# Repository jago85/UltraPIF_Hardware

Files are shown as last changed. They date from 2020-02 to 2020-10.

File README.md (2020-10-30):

# UltraPIF_Hardware
The UltraPIF is a replacement for the N64 PIF-NUS chip.

The PIF-NUS chip responsible for region lockout and copy protection. But it also has essential features like game controller access, cartridge EEPROM access and it includes the MIPS CPU boot rom.

The UltraPIF can replace all functions of the original PIF, but ignores the CIC and thus enables a region-free N64. In addition the UltraPIF comes with an integrated clock generator to compensate the differences of the video clocks for NTSC and PAL consoles. The UltraPIF includes an SPI NOR FLASH used to store the N64 software images. At the moment the FLASH is 16 MiB in size and 99% empty, so there could be features like backup and restore of savegame data or even direct emulation of SI (serial interface) hardware (ControllerPak, cart EEPROM, RTC). An RGB LED replaces the original N64 power LED and is used to show if the N64 is running in NTSC or PAL mode. The color is user programmable.

The project consists of custom PCBs, an FPGA design, an MCU firmware and a bunch of software for the N64 itself.

In this repository you find the KiCad hardware files.

You can find hints for assembly and installation in [the wiki](https://github.com/jago85/UltraPIF_Hardware/wiki).

Interface Board
Adapter Board
LED Board
Interface installed

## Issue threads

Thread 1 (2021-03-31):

Unavailable parts

BadAd84, 2021-03-31:
Hi,

Looking at getting a batch of these made for our store. However, the STM32F070CBT6 and SI5351A-B-GTR are basically not available for a year+ due to shortages.

Is there any sort of alternative or redesign planned? I assume you are seeing this issue too (or maybe not, as not making many??)

jago85, 2021-04-23:
Hi,

sorry for the delay. Due to a lack of time, I'm pretty inactive right now.

Unfortunatelly, I don't have any alternatives or redesign. There may be some compatible devices for the STM32, but I have no idea how to replace the clock generator. Having different parts would also make firmware updates much more complex. I wouldn't have the time for a re-design anyway. I didn't even manage to sort and upload all the software stuff here. (All N64 software and initialization tools are missing here.)

But I know Romi from ModInFrance managed to produce a batch and he can make a good reseller price. You might ask him if you like. [https://shop.modinfrance.fr/fr/nintendo-64/25-115-ultra-pif-nintendo-64.html](https://shop.modinfrance.fr/fr/nintendo-64/25-115-ultra-pif-nintendo-64.html)

BadAd84, 2021-04-23:
That all makes sense, especially around firmware. I have an order in that's just waiting on stock.

Could you send me the extra tools/files required? I could always fork and add it and submit a pull request if it helps you with time etc. I have been maintaining the cdi and 3do rgb mod repos since the owners discontinued them

jago85, 2021-04-26:
Sorry, I cannot send out the firmware at the moment. You should talk to Romi for further details.

Closed 2022-01-19.

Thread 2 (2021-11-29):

Ultra Pif no video but hear slowed down audio

iVirtualPlays, 2021-11-29:
Did the Ultra Pif mod exactly as instructed but doesn’t work. I get no video but hear audio except it’s in slow motion. This Ultra Pif was taken out of my fried Pal Console which i failed to install a ReN64 psu mod and the i put the Ultra Pif into my replacement NTSC motherboard. I then started having this problem once it was transferred. I tried converting the NTSC console into a Pal one by replacing the U7, U15 and the X2 Oscillator, and i get the same problem. Is my Ultra Pif at fault or did i miss something? I don’t know what the JP 4,3,2,1 bridge points are, don’t know what the BL point is on the Ultra Pif board and i get a flashing LD2 Red Status LED with the Green LD3.
By the way my motherboard is NUS-CPU-05 and my faulty Pal motherboard is NUS-CPU (P)01 revision. Hopefully i can fix that motherboard someday.

Here are some pics.
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

iVirtualPlays, 2021-11-29:
By the way my motherboard is NUS-CPU-05 and my faulty Pal motherboard is NUS-CPU (P)01 revision.

jago85, 2021-11-29:
Hi,

the UltraPIF seems to run, but the video clock is not working. Did you remove the load capacitors from X1 on the back of the motherboard? (C39, C40)

Could also be a bad contact in the connector. Sometimes I need to clean them with Isopropyl alcohol.

X2 and U15 are for the RDRAM-Clock. These parts should be the same for PAL and NTSC. Replacing them will not have any effect.

iVirtualPlays, 2021-11-29:
Thanks looks like i may have screwed up the adaptor board. As i desoldered it off my dead N64 using a rework station, the connector is a bit burned. I tried reflowing it with drag soldering and i ended up bridging every joint. Can’t seem to unbridge them since the gaps are too small. So do you know where i can purchase a replacement adaptor board?

Sent from my iPhone

On 29 Nov 2021, at 19:03, Jan Goldacker ***@***.***> wrote:

Hi,

the UltraPIF seems to run, but the video clock is not working. Did you remove the load capacitors from X1 on the back of the motherboard? (C39, C40)

Could also be a bad contact in the connector. Sometimes I need to clean them with Isopropyl alcohol.

X2 and U15 are for the RDRAM-Clock. These parts should be the same for PAL and NTSC. Replacing them will not have any effect.

—
You are receiving this because you authored the thread.
Reply to this email directly, view it on GitHub<https://github.com/jago85/UltraPIF_Hardware/issues/2#issuecomment-981926268>, or unsubscribe<https://github.com/notifications/unsubscribe-auth/AQAQAAXFZOA5QLP5DHJM33LUOPFAHANCNFSM5I7LFBQQ>.
Triage notifications on the go with GitHub Mobile for iOS<https://apps.apple.com/app/apple-store/id1477376905?ct=notification-email&mt=8&pt=524675> or Android<https://play.google.com/store/apps/details?id=com.github.android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>.

iVirtualPlays, 2021-11-29:
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

jago85, 2021-11-29:
You may ask Romi from ModInFrance https://shop.modinfrance.fr/fr/

Yeah, it's quite difficult to remove these boards intact.

You are not from Germany, are you?

iVirtualPlays, 2021-11-29:
No i’m from the UK. I spoke to him they just have the connectors. But will need to figure a way to solder those on. Would be preferred if i can get a preassemble board.

iVirtualPlays, 2021-11-29:
Looks like i will be able to order some replacement adaptor boards, will see if that fixes it. Thanks.

Closed 2022-01-19.

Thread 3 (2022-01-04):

Bad Sync on NTSC games

ZXPortugal, 2022-01-04:
Hi! I own a Jap RGB capable N64, whitch i have a bortis RGB amp installed. Before the Ultra Pif was installed, everything was working ok.
Now with the Ultra Pif i have the following issues:

Menu boots fine with PAL settings and all is ok, PAL games works like charm.
When select NTSC for the menu or NTSC game, i cant get sync.

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

Thanks.

jago85, 2022-01-05:
I think your FSEL signal is somehow tight to GND. Can you check this? The problem might be in one of the connectors as this signal goes between two GND connections.

ZXPortugal, 2022-01-05:
Hi. I have checked and have 2 readings.

I have tested the FSEL to see if gives me GND signal.
With the Ultra Pif removed, i have no ground signal betwen FSEL and GND (used the pin 2 of the MX8330) but with the interface mounted i have a small reading on the multímeter continuity between FSEL and GND

Thanks in advance

Obter Outlook para Android<https://aka.ms/AAb9ysg>
________________________________
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

jago85, 2022-01-05:
So, it looks as there is a short on the Interface board. You can verify this by removing the board and then measure continuity from U1 pin 6 to GND.
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

Maybe there is a solder bridge here:
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

I think you have 3 options:

1. Find and remove the short by yourself
2. Ask your seller for a replacement
3. Use the alternative (not yet documented) installation method that does not require FSEL.
   - close JP1 on the Interface
   - directly connect XTAL to VCLK
      - Lift and isolate pin 1 of the MX8330
      - Then connect XTAL to the VCLK pad on the motherboard
      - Pin 1 stays unconnected

ZXPortugal, 2022-01-06:
Hi!

Have have checked for any bridges and found none.
So i testes the experimental method.

Shorted JP1, lifted PIN 1 of the mx8330, solder the Wire from XTAL to VCLK of NUS IC, and have sucess!!

Now NTSC is working and PAL! Thanks

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
![Uploading IMG_20220106_155955.jpg…]()

jago85, 2022-01-09:
Hi!
Great news! I still wonder why FSEL doesn't work. If it's not a short, maybe there's a problem with the contact or a dead pin. Anyway, I'm glad it's working now.

Closed 2022-01-19.

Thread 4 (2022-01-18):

Analogue audio drop out UltraPIF + N64Digital

ConsoleRefresh, 2022-01-18:
Hi I have a problem. I’ve installed an UltraPIF acquired recently from ModinFrance with N64Digital on a Pal board. I’ve wired up the N64Digital to control the video clock speed and it works as expected. The N64Digital output is beautiful and I adore it. Problem is the analogue audio always drops out after 12-15 mins of play affecting RGB / composite. The composite output for NTSC games is also black and white which isn’t a problem for me but wondering if that indicates an underlying problem. Any help will be greatly appreciated.

jago85, 2022-01-19:
Hi,

I don't have an N64Digital to test this. You shouldn't use the video clock from the N64Digital when you have an UltraPIF. The UltraPIF generates it's own clock.

What N64 motherboard revision do you have?

I don't have any idea what's wrong with your audio. The UltraPIF should not affect the audio.

So you still have the audio on HDMI?

If you want to use Composite Video, you have the connect the NTSC/PAL select signal of the video encoder to FSEL. I just added this information to the Installation Guide in the wiki. https://github.com/jago85/UltraPIF_Hardware/wiki/Installation#composites-video-ntscpal-switch

ConsoleRefresh, 2022-01-19:
Hi thanks for getting back to me. It’s a Pal 01 board. The HDMI audio is flawless. On analogue after 12 mins or so the audio quietens, disappears and occasionally comes back for a few milliseconds. If I then switch over to HDMI the audio is still fine. I’ve tried different analogue leads and it’s definitely the console’s audio that drops out and not anything else. Re clock control. I was advised by ModinFrance to use the N64Digital clock control as there was an issue with UltraPIF controlling the clock with N64D installed. Is this not the case? The N64Digital automatically detecting the region and clock control works beautifully with UltraPIF. Could the audio problem be the console’s amplifier drops out? This audio problem also happens on another console I’ve modded the same way. I’m perplexed.

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

jago85, 2022-01-19:
Hi,

I have a PAL-01 here modded with UltraPIF and N64Adv (RGB mod). Never had any problems with the audio there.

If there is audio on HDMI, then it must drop out somewhere from U1 to U2. I do not have any experience how this subsystem works. Do you have an oscilloscope to check the analogue waveforms?
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

Audio L goes from U1.4 to C32, from C32 to U2.12. Audio R goes from U1.1 to C31, from C31 to U2.3. Then from U2 left audio leaves at pin 8 and right at pin 7.
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

Also, I'd check the 12V on U2.1. Did you use the same power supply for your second console? I'd be super surprised if this issue would be caused by the UltraPIF. The N64Digital is directly connected to the digital audio (U9 pin 6, 7, 10).

I'll ask ModInFrance about the clock. The clock from UltraPIF was to week to drive the N64Digital. I thought the issue was fixed with the firmware changes. I said, I don't know much about the N64Digital. So, I don't understand how it could ever detect the region? According to my information, you have to set the clock manually via Bluetooth. When using a flash cart, the N64Digital cannot know what game you are going to play. You have to select the region in the UltraPIF before starting the flash cart and the N64Digital will not see anything of this. Maybe I missed something, but at the moment this doesn't make sense to me.

jago85, 2022-01-19:
Also, on the PAL-01 board, the clock strength is not a problem, because it has the MX8330 and the video clock doesn't need to be driven directly by the UltraPIF.

ConsoleRefresh, 2022-01-25:
Hi thank you for all the info. The problem seems to have resolved itself on both consoles so it must be a dodgy PSU as the chances of both consoles miraculously resolving themselves at the same time seems ridiculous. I’ve re-capped the PSU now and hopefully it’ll never happen again!

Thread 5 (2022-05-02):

Interaction with Everdrive X7 (UltraCIC-III) and booting PAL ROMs

crozone, 2022-05-02:
I am looking to install the UltraPIF into a PAL N64 to make it multi-region. The system will see use with an Everdrive X7.

I'm hoping just to clarify the behaviour of the UltraPIF in certain scenarios when used with the Everdrive X7 or similar flash cart. It's a bit complicated because the Everdrive does region detection at boot, but it can also launch any region of game after it has started up. I'm especially wondering what the behaviour will be if I launch a PAL game from an Everdrive X7 (UltraCIC-III) on a UltraPIF modded system.

Here are my current assumptions, I'm hoping if you could offer some guidance on whether they are correct or not:

### 1: UltraCIC-III will always choose NTSC on UltraPIF

My rudimentary understanding of the UltraCIC-III is that it achieves automatic region detection by first attempting to boot into NTSC mode, and if that fails, it switches over to PAL mode and reboots.

I *think* this is the UltraCIC-III code that is running in the Everdrive, and it has NTSC mode set as the initial region:

https://github.com/ManCloud/UltraCIC-III/blob/16fd1eecd8528ab2d7fd0490f24fb7738017bd39/UltraCIC-III.asm#L1038

So it looks like it'll always boot into NTSC mode when used with UltraPIF?

### 2: UltraPIF uses the CIC check to set frequencies

This one I'm not really sure about from looking at the project, but does the UltraPIF use the CIC check to set the NTSC/PAL mode (FSEL and clock, etc)? Or does it choose the mode based on the actual game behavior?

### 3: Booting PAL games

The Everdrive X7 is capable of booting PAL games on an NTSC console, and vice versa, through some magic that the Everdrive firmware does. On an un-modded N64 this leads to some weird video output because the frequencies are slightly off and the video encoder chip is still set to the console's region. I believe this causes PAL on NTSC to output as NTSC50, and NTSC on PAL to output as PAL60, and TVs don't always deal with this very well.

My assumption is that the UltraPIF won't/can't know that the Everdrive is actually booting a PAL game from NTSC mode, and will therefore always stay in NTSC mode. This will lead to PAL games booted from the Everdrive to behave as if they're running on an un-modded NTSC system, with the weird video output. Am I correct on this, or does the UltraPIF derive the region via some other method?

Thank you for any assistance you can offer.

jago85, 2022-05-07:
Hi,

the UltraPIF doesn't care about the CIC . You don't even need to have a CIC installed.

The region is setup in the UltraPIF menu everytime before booting a ROM. The UltraPIF determines the region based on the country code in the ROM header to make a pre-selection of the correct region. If I remember correctly, the Everdrive has an empty country code. In this case the UltraPIF can eighter use a fixed region or remember the last region.

It's correct, that the UltraPIF doesn't know when the ED switches the region. So, if you want to play PAL games you have to start the ED in PAL mode (selected in the UltraPIF menu).

The ED could send commands to the UltraPIF and actively reset into the other region, but this is not implemented at the moment.

Ok, I hope this short response answers your question. Feel free to ask more if it is unclear.

crozone, 2022-05-09:
Thanks! I wasn't aware that the UltraPIF implemented its own menu at boot. I finally found a video of it in action [here](https://youtu.be/k5jYbVk9AjA?t=961), and it all makes sense now.

> It's correct, that the UltraPIF doesn't know when the ED switches the region. So, if you want to play PAL games you have to start the ED in PAL mode (selected in the UltraPIF menu).

That's exactly what I was wondering, cheers. Looks like an UltraPIF will work pretty well with an ED then!

Closed 2022-05-09.

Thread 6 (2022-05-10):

MX8330 and MX9911

Yohko, 2022-05-10:
I have a PAL N64 (NUS-CPU (P)-01) which has a MX8330 for U15 but a MX9911 for U7. I tried the Direct VLCK method (DENC-NUS) and lifted pin 1 on U7 (MX911) and connected the pad to Xtal (pin 16 on DENC-NUS is connected to FSEL).  However this doesn't give any Video/Audio. Neither Composite/S-Video/RGB or HDMI (have an additional N64Digital installed). Putting pin 1 on U7 back restores all video signals. PAL and NTSC games boot and seem to run under 50 or 60Hz (according to N64Digital). Composite is in color (via RT5x). Lifting Pin 1 on U7 and bridging the jumper  on the N64Digital also works. However here composite is then in black and white. I didn't try and connected stall to the pin 1 pad and have the jumper on the N64digital closed at the same time as that probably will also cause a crash? Any thoughts on this?

jago85, 2022-05-14:
Hi,

hm, have some thouhgts. But it's not totally clear to me.

The MX9911 should not make a difference. It's the same as the MX8330 but has no output on pin 3. When lifting pin 1, the chip is has no influence to the video clock.

Did you close JP1 on UltraPIF for the Direct VCLK method?

As far as I know, the N64Digital does not work with the clock from the UltraPIF. I think it's putting too much load an the line or has too high termination/damping resistance. But I cannot test it, because I don't have one.

Did you test with the N64Digital disconnected? If it doesn't work, maybe the UltraPIF clock output has an issue.

Do you have a scope to meassure the clock?

Did you try the Standard VCLK method? I cannot test this too, becaus I have no MX9911 here.

Yohko, 2022-05-17:
I have JP1 closed. But I never tried the standard method (as I didn't want to remove any parts). Pin1 is lifted and the N64Digital JP on the flex is closed. I got basically the same issue now on an NTSC (US) N64 with the two MX8330. In both cases I ended up using the N64Digital for the clock. I don't have a scope here but I eventually can try and disconnect the N64Digital and connect the UltraPif to Pin1 and see if it works again. Its not that 50/60Hz doesn't work, just that the N64Digital has to be connected to Pin1 instead.

Yohko, 2022-05-24:
I did some work on the NTSC-US N64 today and did some tests again.
(1) N64digital disconnected (only the flex is still attached to the RCP, jp1 on flex is open), Direct VLCK method with Ultrapif (jp1 on ultrapif is closed, xtal connected to pin1 pad on board, pin 1 lifted and disconnected): no picture (composite)
(2) same as above but N64digital attached: no picture
(3) xtal disconnected from pin1 pad, jp1 on N64digital closed: picture for composite as well as RGB and HDMI from N64digital. PAL composite is black and white and flickers as expected. Everything else looks good.

In all three scenarios (1-3) doing boot up LD2 on ultrapif flashes and the power led cycles through the colors.

jago85, 2022-05-26:
Everything you wrote sounds done right. Maybe there really is something wrong with the UltraPIF / the clock gen. Hard to tell without having it here and without the ability to measure something.

I did some tests today. I disconnected the XTAL signal on both installation methods. With the Direct VCLK method the N64 is stuck after boot. LD2 doesn't flash and the power LED doesn't cycle through the colors.
With the Standard Method LD2 flashes and the power LED cycles but everything is slightly slower than normal. This is because the MX8330 outputs some clock even if there is no input.
So I think there must be some clock on your VCLK. Maybe not the right frequency. Can you tell if the power LED color cycling is slower when the clock comes from the UltraPIF? When you then disconnect the clock completely the N64 should stop after boot. (Just to verify that there really isn't anything connected to the clock.)

I don't have any really good ideas now. Maybe you could do some continuity checks.

The wire from XTAL should have continuity to pin 9 on UltraPIF U1.
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

Maybe the FPGA has no connection to JP1 and thus cannot read that it is closed. If JP1 is closed there should be continuity between GND and pin 64 of U2.
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

I have no clue at the moment. But as long as the N64Digital isn't working with the clock from the UltraPIF you cannot use the Direct VCLK method anyway. Eighter you keep using the N64Digital's VCLK or you try the Standard Method. (The N64Digital's clock will work without the removed parts, too.)

Yohko, 2024-05-19:
During the last few years I have now installed the UltraPIF in several systems with UltraHDMI, N64Digital, and GEM. If I don't want to use the "Standard VCLK method" (as I don't want to remove components) then only direct VLCK with JP1 closed, but no wires connected from XTAL to Pin1 will work. FSEL connected to the encoder if I wanted to fix the composite (on a compatible encoder). Others came to the same result. Standard method seems to work but then the HDMI mod looses its functionality to switch the clk. With direct mode it's the other way around (if UltraPIF is not connected to Pin 1, else back picture, e.g. real direct mode is still broken with HDMI mods).
Did you look into this further and maybe tested this with a HDMI mod yourself (e.g. if direct mode can be made functional?

jago85, 2024-05-19:
I'm not sure if I understand everything correctly. Please allow me this question: You don't happen to speak German, do you? Your name sounds like you could be German. No problem if that's not the case. It would just be easier for me to understand and explain the complicated things.

>_only direct VLCK with JP1 closed, but no wires connected from XTAL to Pin1 will work._

Which JP1 do you mean: UltraPIF or N64Digital? If you don't connect XTAL, it is useless to close JP1 on UltraPIF. If you use the clock from the HDMI mod JP1 on the UltraPIF is a Don't Care. XTAL is left unconnected.

>_Standard method seems to work but then the HDMI mod looses its functionality to switch the clk._

Of course, when using the clock from the console it's impossible to use it from the HDMI mod at the same time. If you are using Direct VCLK from UltraPIF you will lose that feature, too. You always have to decide where the clock should come from. But if you have an UltraPIF, I don't see the point of using the HDMI mod to generate that clock. (Except for the fact it doesn't work any other way for some reason).

>_With direct mode it's the other way around (if UltraPIF is not connected to Pin 1, else back picture, e.g. real direct mode is still broken with HDMI mods)._

I don't fully understand this. With direct mode, you mean the HDMI mod driving this clock? From the UltraPIF's point of view, this is not a mode at all. It is simply unused. And yes, it cannot control the clock in this case. As said, you have to make a decision.

>_If only one mod will be able to control the CLK then this is probably how it's supposed to be, e.g. Standard mode if UltraPIF should control it, JP1 closed (but not wired up) if HDMI mod is controlling it._

As said before, when using the clock from HDMI mod the setup of JP1 on UltraPIF doesn't play a rule. Or did you mean JP1 of the N64Digital?

>_Did you look into this further and maybe tested this with a HDMI mod yourself?_

I have several mods based on CPLD or FPGA using that clock. N64 Advanced v2 (HDMI mod), N64 Advanced v1 (RGB mod), N64 RGB mods from F_L_a_S_H. Everything works without problems, regardless of whether the VCLK is output from the MX chip or directly from UltraPIF. I have just tried it with 3 different consoles.

I got reported the N64Digital not liking the VCLK from UltraPIF years ago. I increased the drive strength of the SI5351A (which is generating the clock) to the maximum. It then worked if I remember correctly.

I probably won't have an N64Digital or Retro GEM unless one is made available to me. (It would also be possible to swap an HDMI mod for say 2 UltraPIFs if the devs are interested in a test system with an UltraPIF.) One thing I've done differently is to connect everything via individual wires. I'm not using flex cables as I only have experimental setups here. My wiring looks rather messy and yet it works fine. So my assumption remains that the clock signal may be too strongly attenuated by a resistor in the flex cable or some other component. As long as no one can measure the signal with an oscilloscope as it arrives at the HDMI mod, I have no new ideas.

jago85, 2024-05-19:
Can you follow how the clock line runs from the N64 board to the FPGA of the HDMI mod? Through any resistors? I can see there is at least one resistor on the flex cable where the clock goes through. But I don't know where the signal ends on the FPGA. Is there a termination on the HDMI board? Any R-C combination or something?

You could also try connecting the clock from the UltraPIF to the HDMI board with a dedicated wire. You could also try using an additional separate GND wire with the clock.

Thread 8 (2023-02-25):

Reset Ultrapif settings

Parodius79, 2023-02-25:
How can you reset the ULTRAPIF settings? Upon boot I toggled the 'direct boot to cart' option in the settings, but I do not know how to undo this option or get back to the settings menu afterwards to make any further changes.

Grateful for assistance as I am unable to find any user information online.

jago85, 2023-02-26:
Hi,
you can return to the menu by holding down the reset button for two seconds while the game is running. (Release the button after the RGB LED starts to flash.)

Also, you can get into the menu by booting the N64 without a cartridge.

Hope this helps :)

Parodius79, 2023-02-26:
Yes, that works - thanks!

Closed 2023-02-26.

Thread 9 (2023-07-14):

Flickering screen + hot N64 NTSC mode

Roy-Meijer, 2023-07-14:
I have a PAL N64 with Tim Worthington's N64RGB and I have installed the Ultra PIF chip on it. Now when it switches to NTSC mode, the screen becomes unstable and flickering. I have noticed the flickering is specifically visible on black screens. Also my N64 becomes relatively hot.

My N64 has a MX8350 PLL chip and MAV-NUS video chip. In have installed it with the direct VCLK method and with composite video. First I removed the PIF chip and soldered on the adapter board. Next I connected JP1 of the UltraPIF PCB and then I lifted pin 3 (VLCK) of the PLL chip and connected the pad to XTAL, lifted pin 23 (mode select) of the MAV-NUS chip and connected the lifted pin to FSEL. Finally installed the UltraPIF PCB on the adapter board. Do you have an idea what is wrong?

Roy-Meijer, 2023-07-14:
I found out the flicker issue is related to the N64 RGB mod

Closed 2023-07-14.

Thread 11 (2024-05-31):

Boot to game not working

vraskin2024, 2024-05-31:
Hi Jago85!
I just installed the UltraPIF into my US N64 and everything works great except for the "Boot to Game" option. The "Reset to Game" option works as intended, but after trying every combination of settings I still have to go through the UltraPIF menu. I was wondering if this was a known software issue or maybe something that could be caused by an incorrect installation? I also have Tim Worthington's N64RGB mod installed if that makes a difference.

Thanks!

vraskin2024, 2024-06-01:
Thanks for the quick response!

1. When powered on, it boots to the menu regarding of what settings are selected. When reset via the reset button, it behaves correctly based on the "Reset to Game: On/Off" setting. The "Boot to Game: On/ Off" setting does get saved, it just doesn't get applied.

2. I've tried with a several US games, a Japanese game, and an Everdrive.

3. I'm pretty sure it was on the latest firmware when I got it, but I did a firmware update to the latest version I could find anyway in case that was the issue. Behavior was the same before and after firmware update.

Info:
Build = Mar 10 2021 19:17:13
Menu 0.9.0 FPGA 0.6.0 MCU 0.11.0

Reset Source: 1
Flash Total: 15689 KiB
Flash Used: 113 KiB (0.72%)
Bootcode CRC: 90BB6CB5

DD Test:
Name: [blank]
ID: [blank]
Bootcode CRC: DB1768F5
4KB CRC: F4B32E99
Init PI Set: 00000000
DD Status: 05080508

TV: NTSC
CIC: 83xx

4. I don't see why it would matter, but just in case it makes a difference:
- I didn't connect the RGB LED board, opting to just keep the regular LED.
- The RGB Mod I have does require a wire going to the PIF chip - I think to enable in game reset via controller? Since the original PIF is removed as part of the UltraPIF installation, I just wired it to the pad.

jago85, 2024-06-01:
Thx for the additional information.

There is a newer release over there in the UltraPIF_MCU repo.
https://github.com/jago85/UltraPIF_MCU/releases/download/v0.11.1/fw_updater_fpga_0-6-0_mcu_0-11-1_menu_0-10-1_bootfiles.zip

I would try to update it, but I don't expect any change in behavior related to this issue.

**Reset Source: 1**
This value is interesting because it is checked for the Boot-to-game feature. The value must be 0 (RESET_SOURCE_POR) but it actually is 1 (RESET_SOURCE_BUTTON). Is this the case directly after turning the console on? This could be an explanation.

I think I could reproduce an behavior like that by hitting the reset button just the right moment during boot. Does your RGB mod work without the reset connection? The UltraPIF can trigger a reset via controller too. Just hold A+B+Z+R+L for 2 seconds.

vraskin2024, 2024-06-02:
Success! Removing the wire from the N64RGB board to the PIF pad did the trick! Thank you so much! For anyone reading this, both mods play nicely together aside from this. The N64RGB de-blur function still works and the in game reset works via the UltraPIF mod.

Thank you so much for your help!

Closed 2024-06-02.

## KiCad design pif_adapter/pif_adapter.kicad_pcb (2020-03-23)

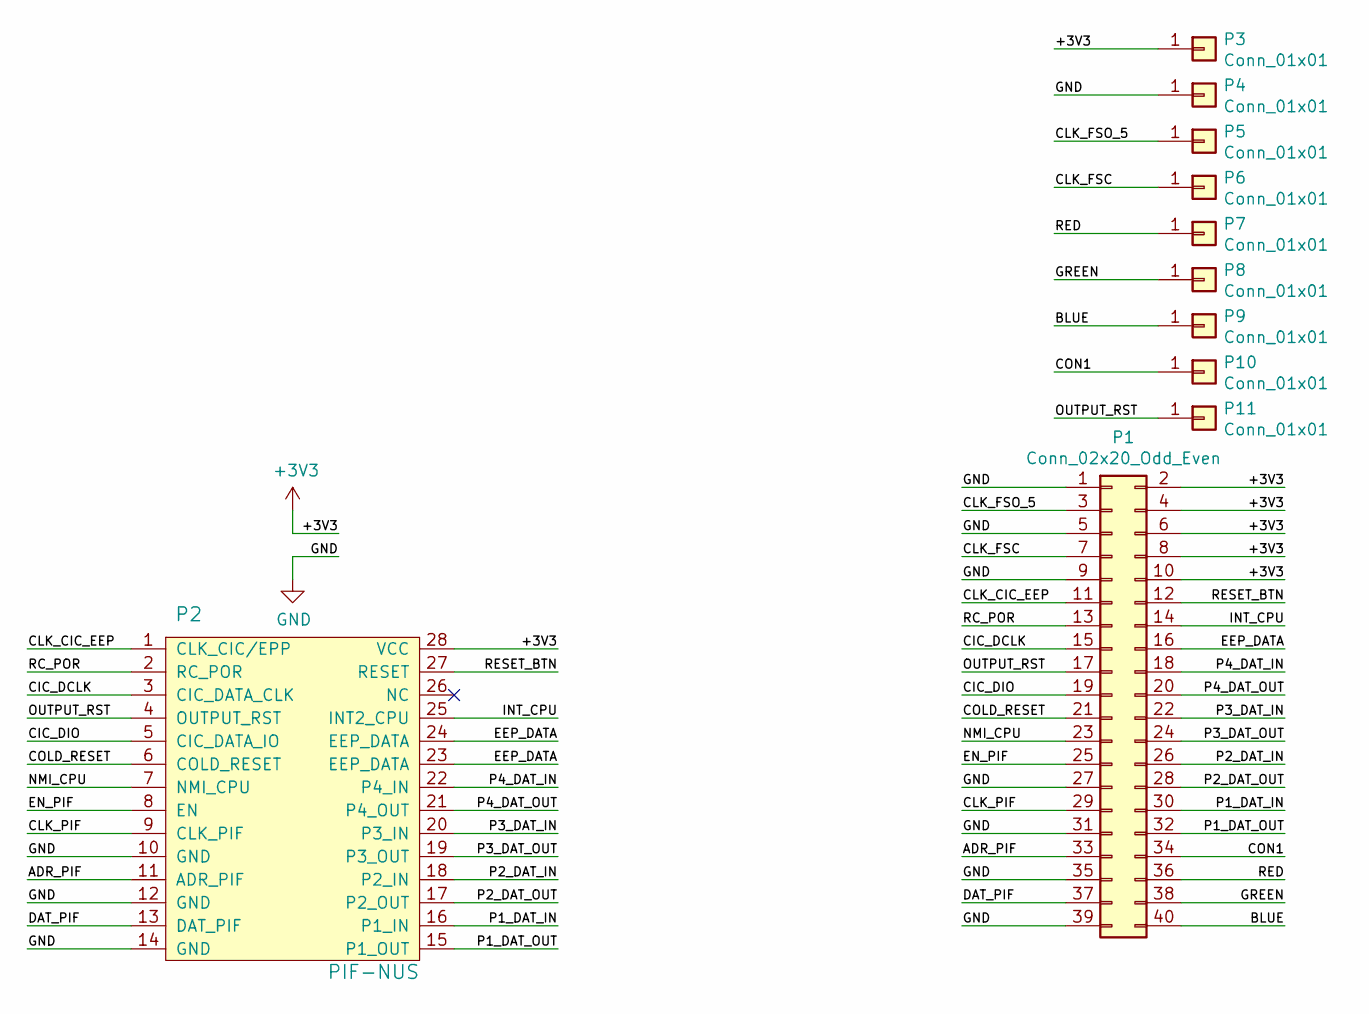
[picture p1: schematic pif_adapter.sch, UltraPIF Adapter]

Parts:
P1: Conn_02x20_Odd_Even; Hirose_DF12D-40DP-0.5V_2x20_P0.50mm_Vertical
P2: PIF-NUS; SOIC28_11mm-Width_Solder_Adapter
P3, P4, P5, P6: Conn_01x01; SolderWirePad_1x01_SMD_1x2mm
P7, P8, P9, P10, P11: Conn_01x01; SolderWirePad_1x01_SMD_0.8x1.3mm

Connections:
+3V3: P1.2, P1.4, P1.6, P1.8, P1.10, P2.28 (VCC), P3.1
/ADR_PIF: P1.33, P2.11 (ADR_PIF)
/BLUE: P1.40, P9.1
/CIC_DCLK: P1.15, P2.3 (CIC_DATA_CLK)
/CIC_DIO: P1.19, P2.5 (CIC_DATA_IO)
/CLK_CIC_EEP: P1.11, P2.1 (CLK_CIC/EPP)
/CLK_FSC: P1.7, P6.1
/CLK_FSO_5: P1.3, P5.1
/CLK_PIF: P1.29, P2.9 (CLK_PIF)
/COLD_RESET: P1.21, P2.6 (COLD_RESET)
/CON1: P1.34, P10.1
/DAT_PIF: P1.37, P2.13 (DAT_PIF)
/EEP_DATA: P1.16, P2.23 (EEP_DATA), P2.24 (EEP_DATA)
/EN_PIF: P1.25, P2.8 (EN)
/GREEN: P1.38, P8.1
/INT_CPU: P1.14, P2.25 (INT2_CPU)
/NMI_CPU: P1.23, P2.7 (NMI_CPU)
/OUTPUT_RST: P1.17, P2.4 (OUTPUT_RST), P11.1
/P1_DAT_IN: P1.30, P2.16 (P1_IN)
/P1_DAT_OUT: P1.32, P2.15 (P1_OUT)
/P2_DAT_IN: P1.26, P2.18 (P2_IN)
/P2_DAT_OUT: P1.28, P2.17 (P2_OUT)
/P3_DAT_IN: P1.22, P2.20 (P3_IN)
/P3_DAT_OUT: P1.24, P2.19 (P3_OUT)
/P4_DAT_IN: P1.18, P2.22 (P4_IN)
/P4_DAT_OUT: P1.20, P2.21 (P4_OUT)
/RC_POR: P1.13, P2.2 (RC_POR)
/RED: P1.36, P7.1
/RESET_BTN: P1.12, P2.27 (RESET)
GND: P1.1, P1.5, P1.9, P1.27, P1.31, P1.35, P1.39, P2.10 (GND), P2.12 (GND), P2.14 (GND), P4.1

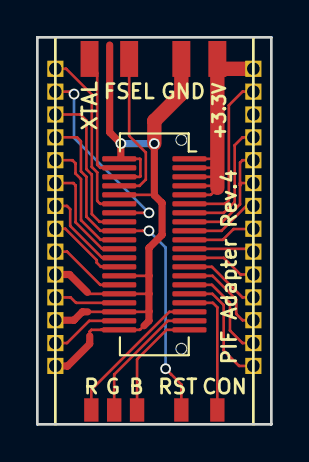
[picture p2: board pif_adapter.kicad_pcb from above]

Board: 2 copper layers, 13.0 x 21.5 mm, 11 parts (0 on the bottom side), 30 nets.

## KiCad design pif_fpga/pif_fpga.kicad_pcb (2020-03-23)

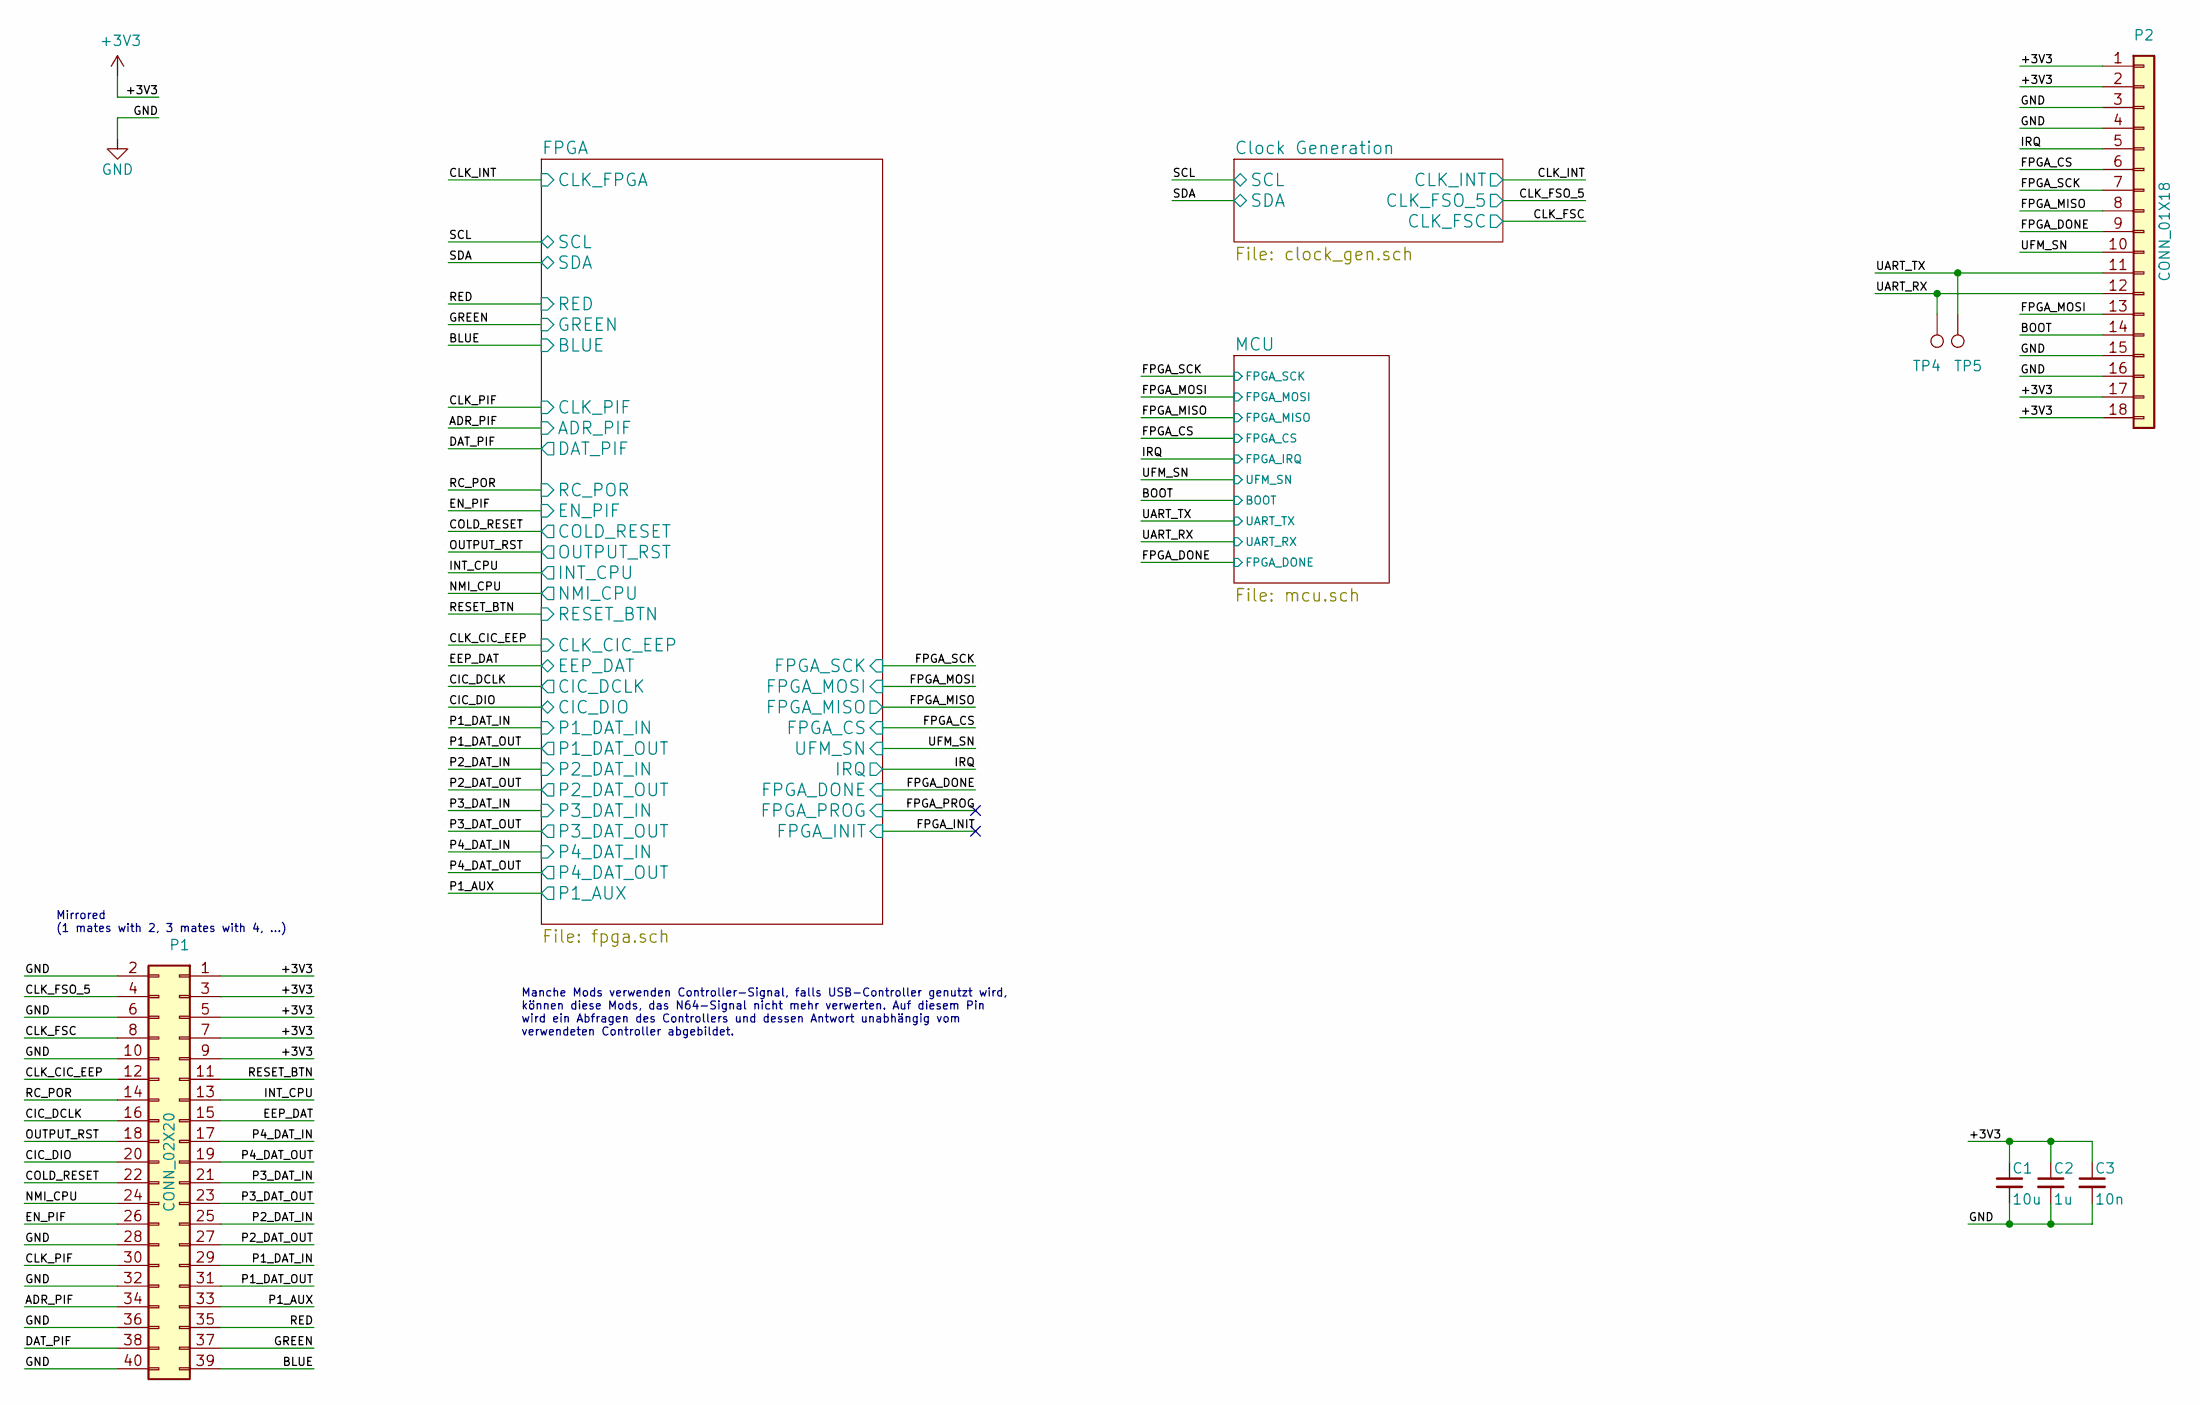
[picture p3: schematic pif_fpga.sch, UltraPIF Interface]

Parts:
C1: 10u; C_0805_2012Metric
C2: 1u; C_0603_1608Metric
C3: 10n; C_0603_1608Metric
P1: CONN_02X20; Hirose_DF12A-40DS-0.5V_2x20_P0.50mm_Vertical
P2: CONN_01X18; Molex_BackFlip_18x0.5mm
TP4, TP5: TestPoint; TP_0.8mm

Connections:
+3V3: C1.1, C2.1, C3.1, P1.1, P1.3, P1.5, P1.7, P1.9, P2.1, P2.2, P2.17, P2.18; also elsewhere on the board
/ADR_PIF: P1.34; also elsewhere on the board
/BLUE: P1.39; also elsewhere on the board
/BOOT: P2.14; also elsewhere on the board
/CIC_DCLK: P1.16; also elsewhere on the board
/CIC_DIO: P1.20; also elsewhere on the board
/CLK_CIC_EEP: P1.12; also elsewhere on the board
/CLK_FSC: P1.8; also elsewhere on the board
/CLK_FSO_5: P1.4; also elsewhere on the board
/CLK_PIF: P1.30; also elsewhere on the board
/COLD_RESET: P1.22; also elsewhere on the board
/DAT_PIF: P1.38; also elsewhere on the board
/EEP_DAT: P1.15; also elsewhere on the board
/EN_PIF: P1.26; also elsewhere on the board
/FPGA_CS: P2.6; also elsewhere on the board
/FPGA_DONE: P2.9; also elsewhere on the board
/FPGA_MISO: P2.8; also elsewhere on the board
/FPGA_MOSI: P2.13; also elsewhere on the board
/FPGA_SCK: P2.7; also elsewhere on the board
/GREEN: P1.37; also elsewhere on the board
/INT_CPU: P1.13; also elsewhere on the board
/IRQ: P2.5; also elsewhere on the board
/NMI_CPU: P1.24; also elsewhere on the board
/OUTPUT_RST: P1.18; also elsewhere on the board
/P1_AUX: P1.33; also elsewhere on the board
/P1_DAT_IN: P1.29; also elsewhere on the board
/P1_DAT_OUT: P1.31; also elsewhere on the board
/P2_DAT_IN: P1.25; also elsewhere on the board
/P2_DAT_OUT: P1.27; also elsewhere on the board
/P3_DAT_IN: P1.21; also elsewhere on the board
/P3_DAT_OUT: P1.23; also elsewhere on the board
/P4_DAT_IN: P1.17; also elsewhere on the board
/P4_DAT_OUT: P1.19; also elsewhere on the board
/RC_POR: P1.14; also elsewhere on the board
/RED: P1.35; also elsewhere on the board
/RESET_BTN: P1.11; also elsewhere on the board
/UART_RX: P2.12, TP4.1; also elsewhere on the board
/UART_TX: P2.11, TP5.1; also elsewhere on the board
/UFM_SN: P2.10; also elsewhere on the board
GND: C1.2, C2.2, C3.2, P1.2, P1.6, P1.10, P1.28, P1.32, P1.36, P1.40, P2.3, P2.4, P2.15, P2.16; also elsewhere on the board

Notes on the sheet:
Mirrored (1 mates with 2, 3 mates with 4, ...)
Manche Mods verwenden Controller-Signal, falls USB-Controller genutzt wird, können diese Mods, das N64-Signal nicht mehr verwerten. Auf diesem Pin wird ein Abfragen des Controllers und dessen Antwort unabhängig vom verwendeten Controller abgebildet.

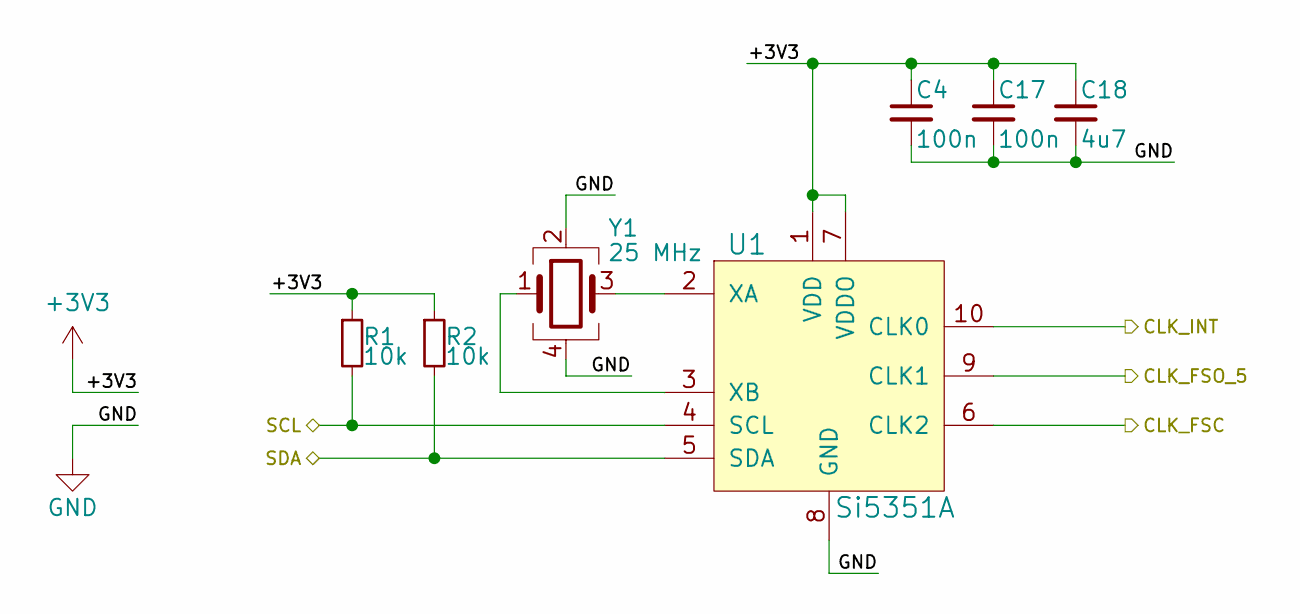
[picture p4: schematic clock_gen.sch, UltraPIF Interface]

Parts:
C4, C17: 100n; C_0603_1608Metric
C18: 4u7; C_0603_1608Metric
R1, R2: 10k; R_0603_1608Metric
U1: Si5351A; MSOP-10_3x3mm_P0.5mm
Y1: 25 MHz; Crystal_SMD_3225-4Pin_3.2x2.5mm

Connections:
+3V3: C4.1, C17.1, C18.1, R1.1, R2.1, U1.1 (VDD), U1.7 (VDDO); also elsewhere on the board
/CLK_FSC: U1.6 (CLK2); also elsewhere on the board
/CLK_FSO_5: U1.9 (CLK1); also elsewhere on the board
/CLK_INT: U1.10 (CLK0); also elsewhere on the board
/SCL: R1.2, U1.4 (SCL); also elsewhere on the board
/SDA: R2.2, U1.5 (SDA); also elsewhere on the board
GND: C4.2, C17.2, C18.2, U1.8 (GND), Y1.2, Y1.4; also elsewhere on the board
unnamed: U1.2 (XA), Y1.3
unnamed: U1.3 (XB), Y1.1

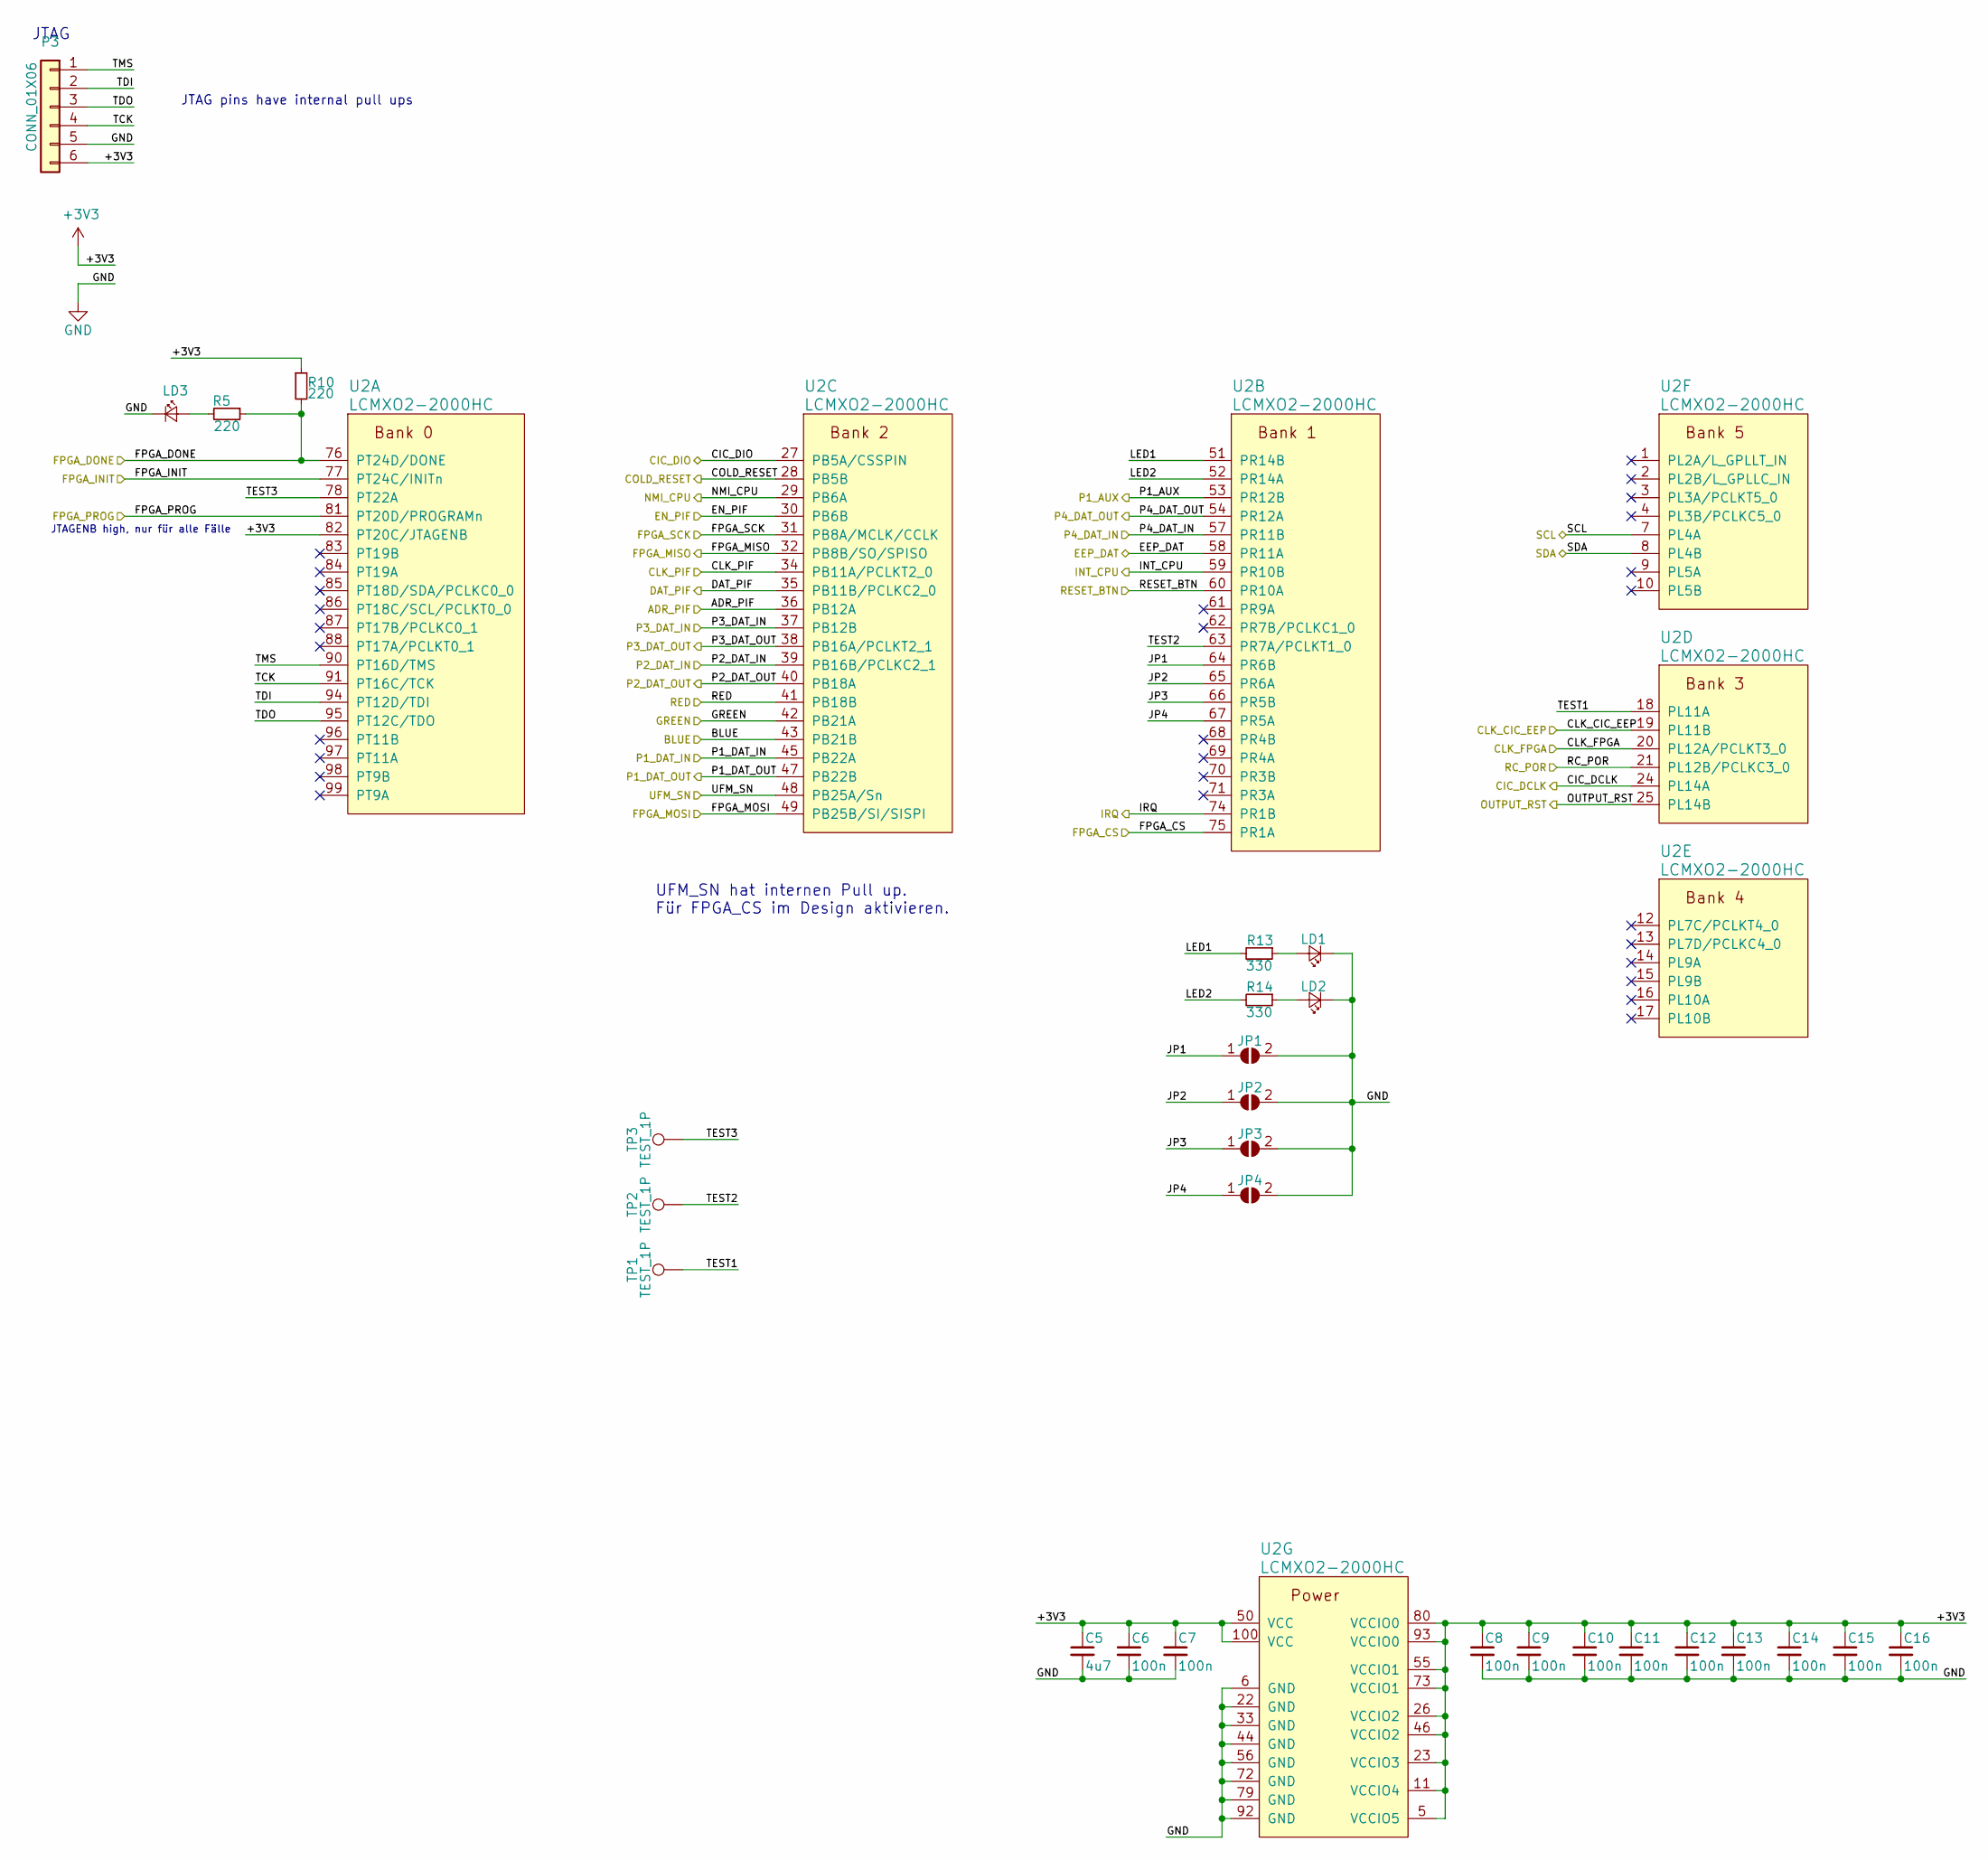
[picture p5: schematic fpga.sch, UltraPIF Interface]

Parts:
C5: 4u7; C_0603_1608Metric
C6, C7, C8, C9, C10, C11, C12, C13, C14, C15, C16: 100n; C_0603_1608Metric
JP1, JP2, JP3, JP4: Jumper_NO_Small; SolderJumper-2_P1.3mm_Open_RoundedPad1.0x1.5mm
LD1, LD2, LD3: LED_Small; LED_0603_1608Metric
P3: CONN_01X06; PinHeader_1x06_P2.54mm_NoSolder
R5, R10: 220; R_0603_1608Metric
R13, R14: 330; R_0603_1608Metric
TP1, TP2, TP3: TEST_1P; TP_0.8mm
U2: LCMXO2-2000HC; TQFP-100_14x14mm_P0.5mm

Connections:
+3V3: C5.1, C6.1, C7.1, C8.1, C9.1, C10.1, C11.1, C12.1, C13.1, C14.1, C15.1, C16.1, P3.6, R10.1, U2.5 (VCCIO5), U2.11 (VCCIO4), U2.23 (VCCIO3), U2.26 (VCCIO2), U2.46 (VCCIO2), U2.50 (VCC), U2.55 (VCCIO1), U2.73 (VCCIO1), U2.80 (VCCIO0), U2.82 (PT20C/JTAGENB), U2.93 (VCCIO0), U2.100 (VCC); also elsewhere on the board
/ADR_PIF: U2.36 (PB12A); also elsewhere on the board
/BLUE: U2.43 (PB21B); also elsewhere on the board
/CIC_DCLK: U2.24 (PL14A); also elsewhere on the board
/CIC_DIO: U2.27 (PB5A/CSSPIN); also elsewhere on the board
/CLK_CIC_EEP: U2.19 (PL11B); also elsewhere on the board
/CLK_INT: U2.20 (PL12A/PCLKT3_0); also elsewhere on the board
/CLK_PIF: U2.34 (PB11A/PCLKT2_0); also elsewhere on the board
/COLD_RESET: U2.28 (PB5B); also elsewhere on the board
/DAT_PIF: U2.35 (PB11B/PCLKC2_0); also elsewhere on the board
/EEP_DAT: U2.58 (PR11A); also elsewhere on the board
/EN_PIF: U2.30 (PB6B); also elsewhere on the board
/FPGA/JP1: JP1.1 (A), U2.64 (PR6B)
/FPGA/JP2: JP2.1 (A), U2.65 (PR6A)
/FPGA/JP3: JP3.1 (A), U2.66 (PR5B)
/FPGA/JP4: JP4.1 (A), U2.67 (PR5A)
/FPGA/LED1: R13.2, U2.51 (PR14B)
/FPGA/LED2: R14.2, U2.52 (PR14A)
/FPGA/TCK: P3.4, U2.91 (PT16C/TCK)
/FPGA/TDI: P3.2, U2.94 (PT12D/TDI)
/FPGA/TDO: P3.3, U2.95 (PT12C/TDO)
/FPGA/TEST1: TP1.1, U2.18 (PL11A)
/FPGA/TEST2: TP2.1, U2.63 (PR7A/PCLKT1_0)
/FPGA/TEST3: TP3.1, U2.78 (PT22A)
/FPGA/TMS: P3.1, U2.90 (PT16D/TMS)
/FPGA_CS: U2.75 (PR1A); also elsewhere on the board
/FPGA_DONE: R5.1, R10.2, U2.76 (PT24D/DONE); also elsewhere on the board
/FPGA_MISO: U2.32 (PB8B/SO/SPISO); also elsewhere on the board
/FPGA_MOSI: U2.49 (PB25B/SI/SISPI); also elsewhere on the board
/FPGA_SCK: U2.31 (PB8A/MCLK/CCLK); also elsewhere on the board
/GREEN: U2.42 (PB21A); also elsewhere on the board
/INT_CPU: U2.59 (PR10B); also elsewhere on the board
/IRQ: U2.74 (PR1B); also elsewhere on the board
/NMI_CPU: U2.29 (PB6A); also elsewhere on the board
/OUTPUT_RST: U2.25 (PL14B); also elsewhere on the board
/P1_AUX: U2.53 (PR12B); also elsewhere on the board
/P1_DAT_IN: U2.45 (PB22A); also elsewhere on the board
/P1_DAT_OUT: U2.47 (PB22B); also elsewhere on the board
/P2_DAT_IN: U2.39 (PB16B/PCLKC2_1); also elsewhere on the board
/P2_DAT_OUT: U2.40 (PB18A); also elsewhere on the board
/P3_DAT_IN: U2.37 (PB12B); also elsewhere on the board
/P3_DAT_OUT: U2.38 (PB16A/PCLKT2_1); also elsewhere on the board
/P4_DAT_IN: U2.57 (PR11B); also elsewhere on the board
/P4_DAT_OUT: U2.54 (PR12A); also elsewhere on the board
/RC_POR: U2.21 (PL12B/PCLKC3_0); also elsewhere on the board
/RED: U2.41 (PB18B); also elsewhere on the board
/RESET_BTN: U2.60 (PR10A); also elsewhere on the board
/SCL: U2.7 (PL4A); also elsewhere on the board
/SDA: U2.8 (PL4B); also elsewhere on the board
/UFM_SN: U2.48 (PB25A/Sn); also elsewhere on the board
GND: C5.2, C6.2, C7.2, C8.2, C9.2, C10.2, C11.2, C12.2, C13.2, C14.2, C15.2, C16.2, JP1.2 (B), JP2.2 (B), JP3.2 (B), JP4.2 (B), LD1.1 (K), LD2.1 (K), LD3.1 (K), P3.5, U2.6 (GND), U2.22 (GND), U2.33 (GND), U2.44 (GND), U2.56 (GND), U2.72 (GND), U2.79 (GND), U2.92 (GND); also elsewhere on the board
unnamed: LD1.2 (A), R13.1
unnamed: LD2.2 (A), R14.1
unnamed: LD3.2 (A), R5.2

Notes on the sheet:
JTAG
UFM_SN hat internen Pull up. Für FPGA_CS im Design aktivieren.
JTAGENB high, nur für alle Fälle
JTAG pins have internal pull ups

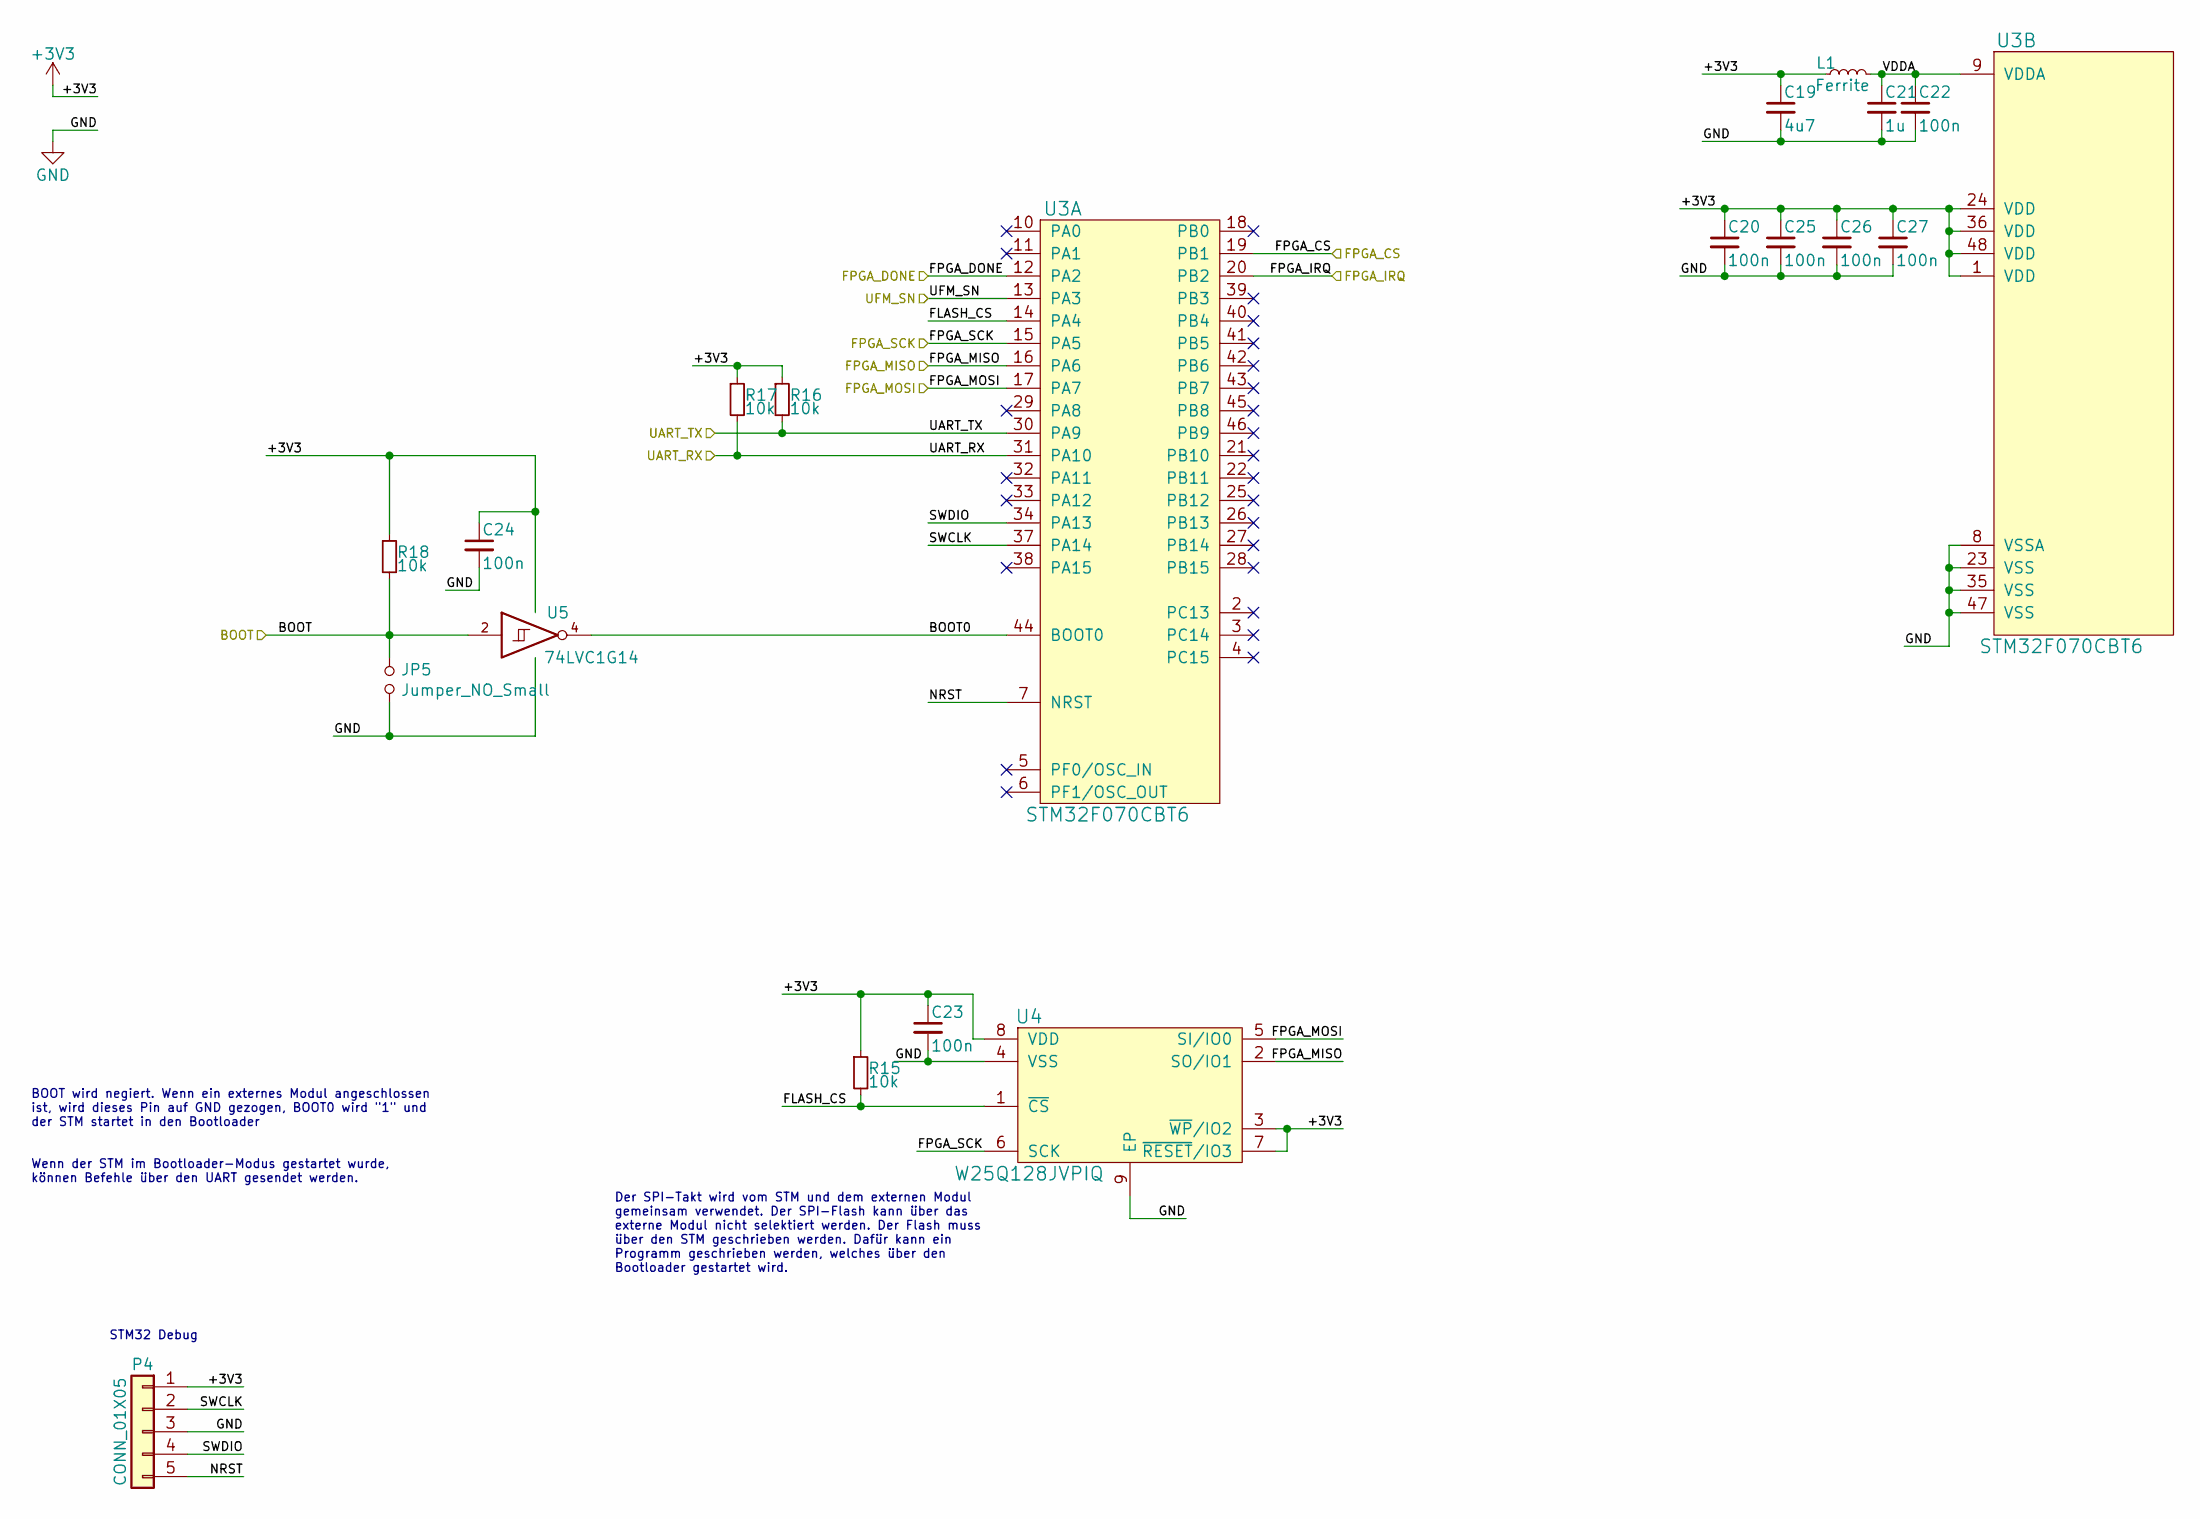
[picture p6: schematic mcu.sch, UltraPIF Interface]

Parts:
C19: 4u7; C_0603_1608Metric
C20, C23, C24, C25, C26, C27: 100n; C_0402_1005Metric
C21: 1u; C_0603_1608Metric
C22: 100n; C_0603_1608Metric
JP5: Jumper_NO_Small; SolderJumper-2_P1.3mm_Open_RoundedPad1.0x1.5mm
L1: Ferrite; L_0603_1608Metric
P4: CONN_01X05; PinHeader_1x05_P2.54mm_NoSolder
R15, R16, R17, R18: 10k; R_0603_1608Metric
U3: STM32F070CBT6; LQFP-48_7x7mm_P0.5mm
U4: W25Q128JVPIQ; DFN-8-1EP_6x5mm_P1.27mm_EP2x2mm
U5: 74LVC1G14; SOT-353_SC-70-5

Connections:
+3V3: C19.1, C20.1, C23.1, C24.1, C25.1, C26.1, C27.1, L1.1, P4.1, R15.1, R16.1, R17.1, R18.1, U3.1 (VDD), U3.24 (VDD), U3.36 (VDD), U3.48 (VDD), U4.3 (~WP~/IO2), U4.7 (~RESET~/IO3), U4.8 (VDD), U5.5 (VCC); also elsewhere on the board
/BOOT: JP5.1, R18.2, U5.2; also elsewhere on the board
/FPGA_CS: U3.19 (PB1); also elsewhere on the board
/FPGA_DONE: U3.12 (PA2); also elsewhere on the board
/FPGA_MISO: U3.16 (PA6), U4.2 (SO/IO1); also elsewhere on the board
/FPGA_MOSI: U3.17 (PA7), U4.5 (SI/IO0); also elsewhere on the board
/FPGA_SCK: U3.15 (PA5), U4.6 (SCK); also elsewhere on the board
/IRQ: U3.20 (PB2); also elsewhere on the board
/MCU/BOOT0: U3.44 (BOOT0), U5.4
/MCU/FLASH_CS: R15.2, U3.14 (PA4), U4.1 (~CS)
/MCU/NRST: P4.5, U3.7 (NRST)
/MCU/SWCLK: P4.2, U3.37 (PA14)
/MCU/SWDIO: P4.4, U3.34 (PA13)
/MCU/VDDA: C21.1, C22.1, L1.2, U3.9 (VDDA)
/UART_RX: R17.2, U3.31 (PA10); also elsewhere on the board
/UART_TX: R16.2, U3.30 (PA9); also elsewhere on the board
/UFM_SN: U3.13 (PA3); also elsewhere on the board
GND: C19.2, C20.2, C21.2, C22.2, C23.2, C24.2, C25.2, C26.2, C27.2, JP5.2, P4.3, U3.8 (VSSA), U3.23 (VSS), U3.35 (VSS), U3.47 (VSS), U4.4 (VSS), U4.9 (EP), U5.3 (GND); also elsewhere on the board

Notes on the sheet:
STM32 Debug
Wenn der STM im Bootloader-Modus gestartet wurde, können Befehle über den UART gesendet werden.
Der SPI-Takt wird vom STM und dem externen Modul gemeinsam verwendet. Der SPI-Flash kann über das externe Modul nicht selektiert werden. Der Flash muss über den STM geschrieben werden. Dafür kann ein Programm geschrieben werden, welches über den Bootloader gestartet wird.
BOOT wird negiert. Wenn ein externes Modul angeschlossen ist, wird dieses Pin auf GND gezogen, BOOT0 wird "1" und der STM startet in den Bootloader

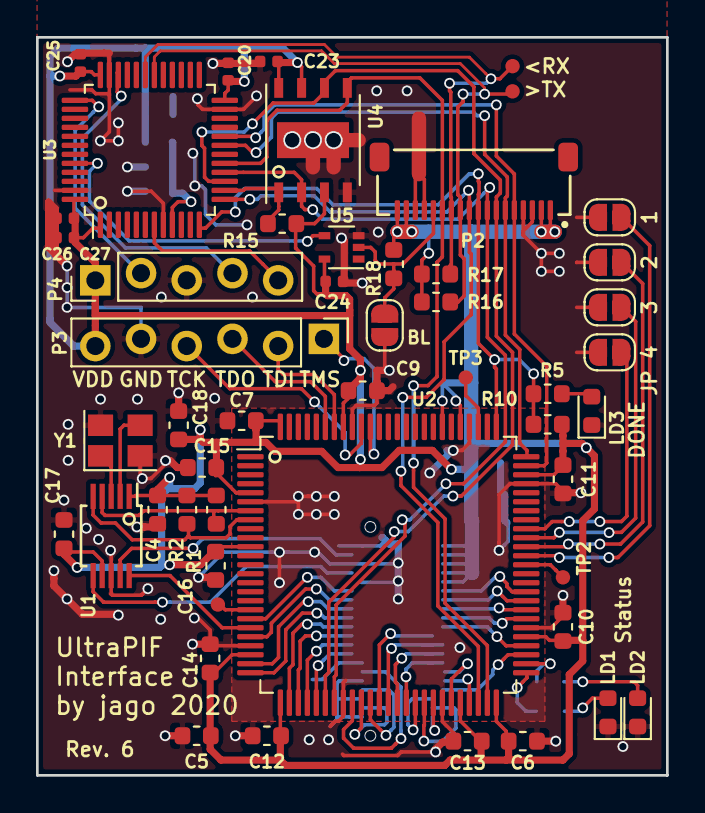
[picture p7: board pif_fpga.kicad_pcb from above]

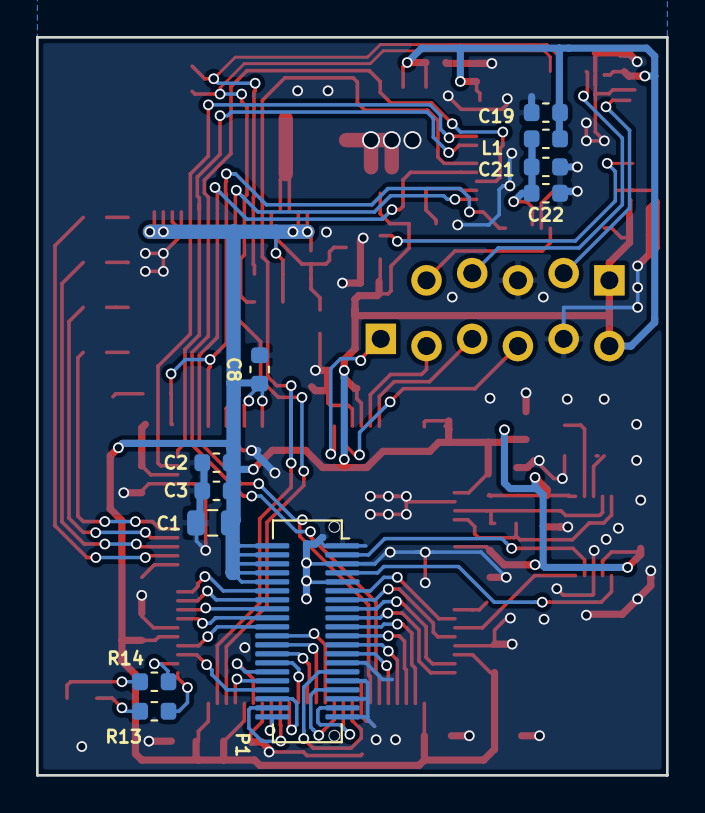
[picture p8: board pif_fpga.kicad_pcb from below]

Board: 2 copper layers, 35.0 x 41.0 mm, 61 parts (11 on the bottom side), 67 nets.

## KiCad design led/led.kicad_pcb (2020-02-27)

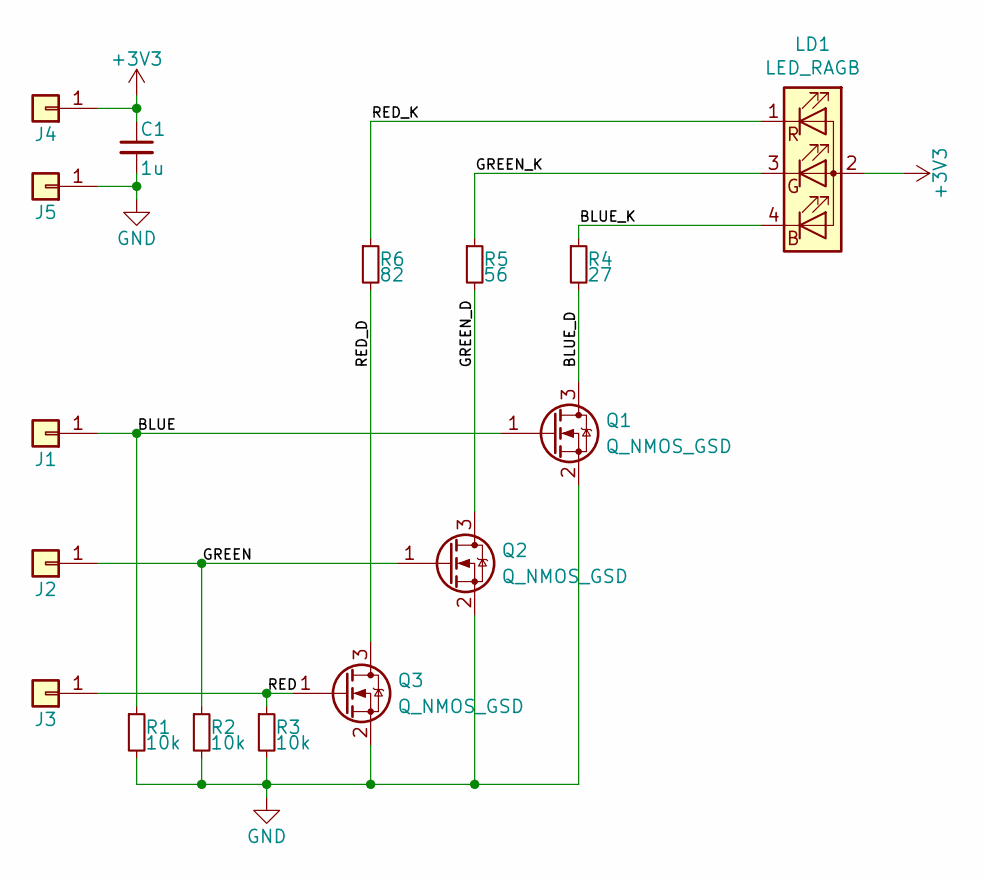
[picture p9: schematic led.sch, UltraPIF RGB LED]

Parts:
C1: 1u; C_0603_1608Metric
J1, J2, J3: CONN_01X01; SolderWirePad_1x01_SMD_0.8x1.3mm
J4, J5: CONN_01X01; SolderWirePad_1x01_Drill0.8mm
LD1: LED_RAGB; LED_D5.0mm-4_RGB
Q1, Q2, Q3: Q_NMOS_GSD; SOT-23
R1, R2, R3: 10k; R_0603_1608Metric
R4: 27; R_0603_1608Metric
R5: 56; R_0603_1608Metric
R6: 82; R_0603_1608Metric

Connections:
+3V3: C1.1, J4.1, LD1.2 (A)
/BLUE: J1.1, Q1.1 (G), R1.1
/BLUE_D: Q1.3 (D), R4.2
/BLUE_K: LD1.4 (BK), R4.1
/GREEN: J2.1, Q2.1 (G), R2.1
/GREEN_D: Q2.3 (D), R5.2
/GREEN_K: LD1.3 (GK), R5.1
/RED: J3.1, Q3.1 (G), R3.1
/RED_D: Q3.3 (D), R6.2
/RED_K: LD1.1 (RK), R6.1
GND: C1.2, J5.1, Q1.2 (S), Q2.2 (S), Q3.2 (S), R1.2, R2.2, R3.2

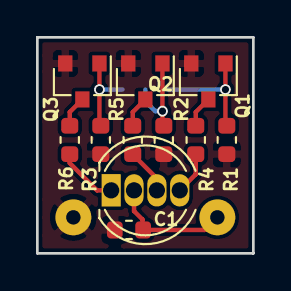
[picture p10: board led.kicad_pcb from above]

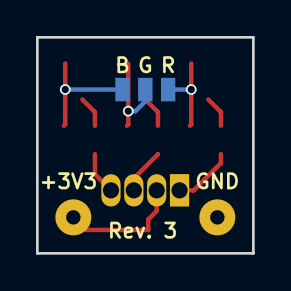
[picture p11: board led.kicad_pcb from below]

Board: 2 copper layers, 12.0 x 12.0 mm, 16 parts (3 on the bottom side), 11 nets.

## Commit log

2020-01-14 Current working states on the way to the next revision
    [clock_gen.sch, fpga.sch, led.kicad_pcb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]
2020-02-26 changed connector to Hirose DF12
    [pif_adapter.kicad_pcb, pif_adapter.sch, pif_fpga.kicad_pcb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]
2020-02-26 improved some wires
    [pif_fpga.kicad_pcb]
2020-02-27 routing changes no copper fill under the connector
    [pif_fpga.kicad_pcb]
2020-02-27 'Rev 6' silk text
    [pif_fpga.kicad_pcb]
2020-02-27 set aux origin and gerber options
    [pif_fpga.kicad_pcb]
2020-03-04 no copper fill under the connector
    [pif_fpga.kicad_pcb]
2020-03-04 - updated revision infos - changed some traces
    [clock_gen.sch, fpga.sch, mcu.sch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]
2020-03-04 improved ground trace
    [pif_adapter.kicad_pcb]
2020-03-04 - updated revision info - cut edges through vias
    [pif_adapter.kicad_pcb, pif_adapter.sch]
2020-03-04 set aux origin
    [pif_adapter.kicad_pcb]
2020-03-07 - moved jumpers a bit downwards - no cupper fill under P2
    [pif_fpga.kicad_pcb]
2020-03-07 removed via under LD3 silk
    [pif_fpga.kicad_pcb]
2020-03-07 removed unnecessary via from power rail
    [pif_fpga.kicad_pcb]
2020-03-14 routing changes
    [pif_adapter.kicad_pcb]
2020-03-15 changed the PCB-edges for manual via cutting
    [pif_adapter.kicad_pcb]
2020-03-15 changed plot settings
    [pif_adapter.kicad_pcb]
2020-03-15 changed the PCB-edges for manual via cutting changed plot settings
    [pif_adapter.kicad_pcb]
2020-03-15 changes some traces under the connector connected solder jumpers to GND
    [pif_fpga.kicad_pcb]
2020-03-15 connected solder jumpers to GND
    [pif_fpga.kicad_pcb]
2020-03-23 set revision in sheets
    [clock_gen.sch, fpga.sch, mcu.sch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]
